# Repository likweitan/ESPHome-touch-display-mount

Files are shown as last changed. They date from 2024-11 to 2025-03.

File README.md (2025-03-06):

# 2.8" ILI9341 Touch Display Enclosure for ESP32 with Home Assistant Integration

This project provides ESPHome config files and 3D-printable files for an enclosure designed to house a 2.8" ILI9341 touch display. Compatible with standalone 2.8" ILI9341 touch display connected to an ESP32 board or using the ESP32-2432S028 (integrating an ESP32 Wroom module and ILI9341 display on one board), this setup serves as an external, touchscreen-enabled display for your Home Assistant environment.

The enclosure is designed for mounting beneath a desk and includes a swivel joint, allowing for easy adjustments to the viewing angle while keeping all cables neatly concealed for a clean, streamlined look. The touchscreen offers multiple customizable buttons linked to Home Assistant automations, making it easy to control functions such as lighting—and you’re free to create additional buttons as desired.

The joint supports an adjustable tilt of +/- 35 degrees up and down. The display’s positioning tension can be fine-tuned by adjusting the screw tightness. The screw hole is deliberately sized slightly smaller than the M4 screw, requiring a bit of force during insertion to ensure a secure hold that prevents any looseness.

Simply print the files and flash the firmware to the ESP using ESPHome, connect it to Home Assistant.

The images show the version with an ESP32-2432S028. I recommend using the ESP32-2432S028 as its just the power cable you need to pass-thru into the case and everything else is hidden. Down below you'll find some images of the ILI9341 display with an external ESP32.

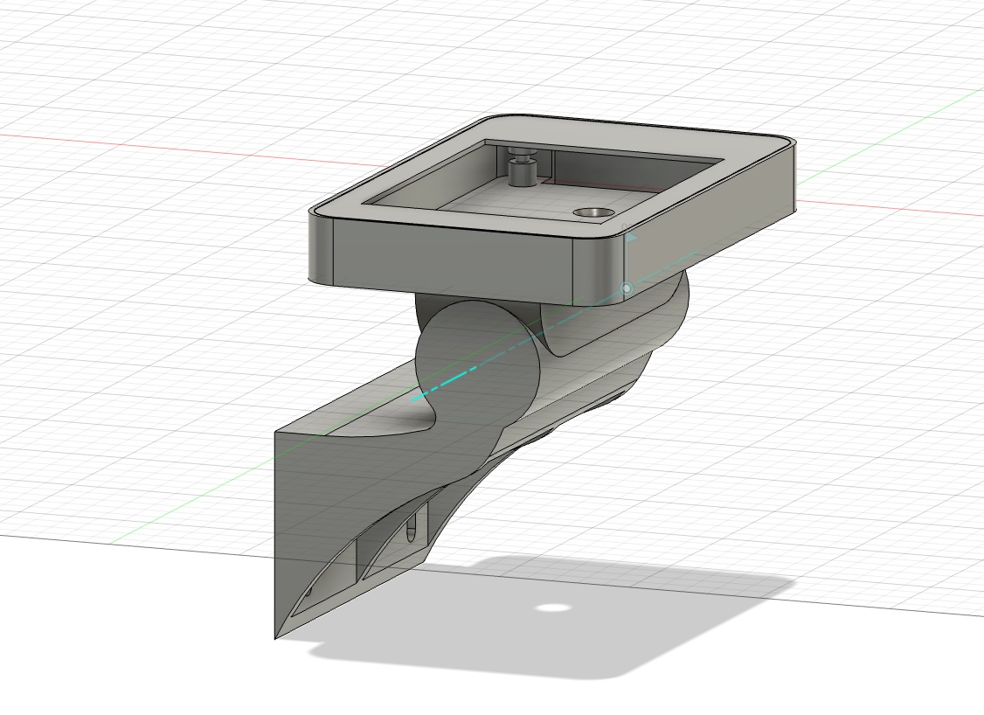
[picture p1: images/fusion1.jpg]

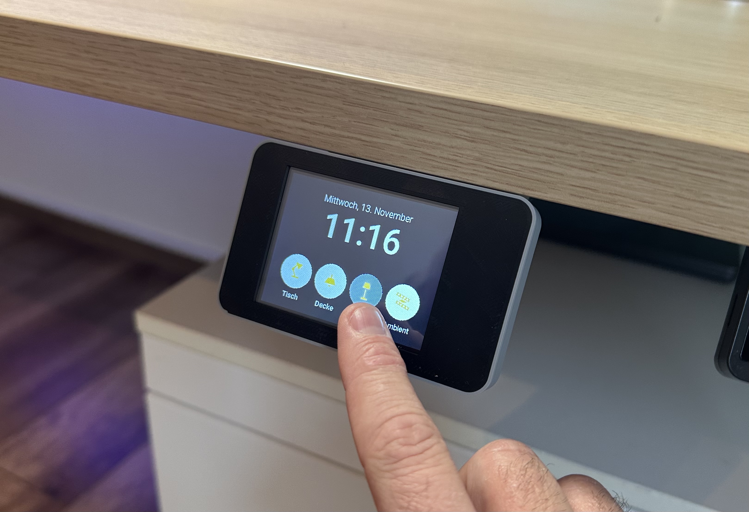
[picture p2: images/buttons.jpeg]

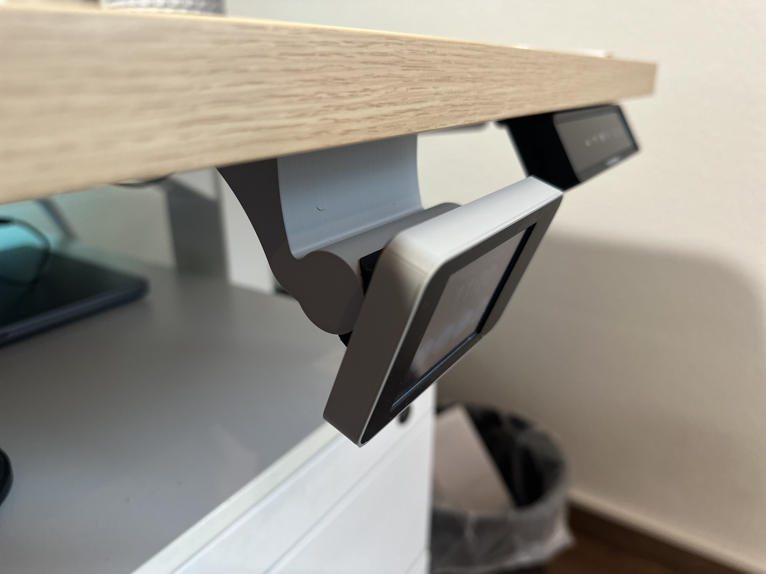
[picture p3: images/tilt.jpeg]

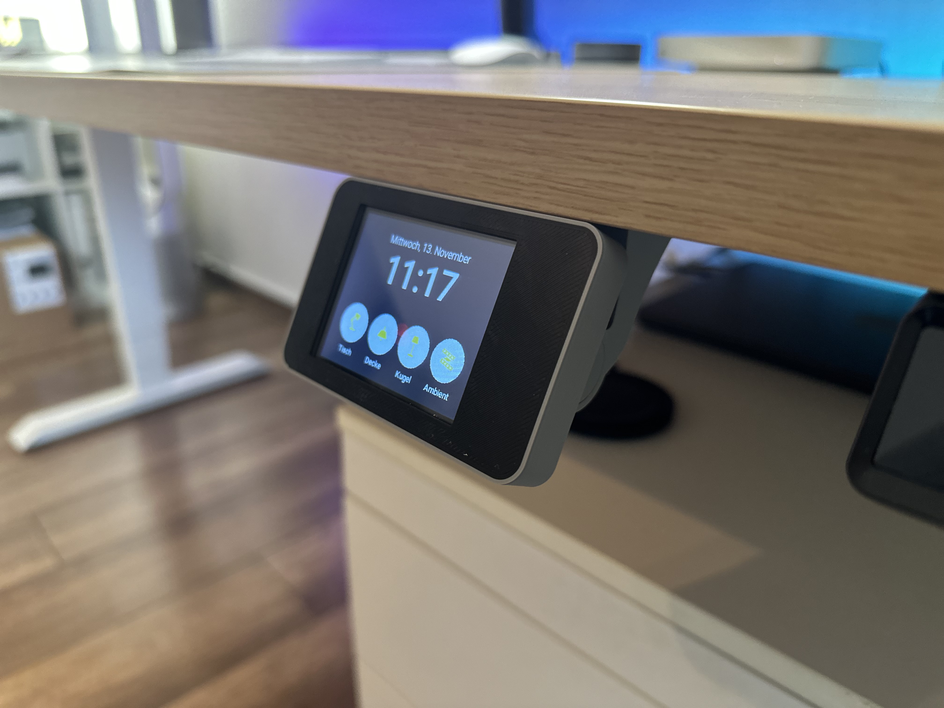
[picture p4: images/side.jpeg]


### Features:

- Customizable 3D-printed enclosure with hidden cable design for a clean setup
- Swivel joint for adjustable viewing angles
- Supports 2.8" ILI9341 touch display, compatible with ESP32 or ESP32-2432S028 (includes ESP32 Wroom and display on one board)
- Connect to Home Assistant compatibility to control automations such as lighting
- Using [ESPHome](https://www.esphome.io) which makes it easy to code and modify for your needs

## Parts needed

| Part | Price | Comment |
|---|---|---|
| ESP32-2432S028			 | 15$ | 2.8" ILI9341 with integrated ESP |
| 2x M4 3.5x16 screw (flathead)| 0.10$ | Screws to connect the mount case with the base  |

or

| Part | Price | Comment |
|---|---|---|
| 2.8" ILI9341 			 | 8$ | 2.8" ILI9341 |
| ESP32 Wroom 32D 		 | 8$ | or some ESP32 |
| 2x M4 3.5x16 screw (flathead)| 0.10$ | Screws to connect the mount case with the base  |

## How
- Flash your ESP32 via ESPHome and use the yaml from the esphome folder. Adjust to your needs
- Print the parts. 
- Use two M4 screws to attach the display case and the base
- *Connect all pins (when using a solo display with an ESP32)

## HomeAssistant
- Create some automations in home assistant using the exposed buttons as trigger.
<br/>
<br/>
<br/>
# Options

## a) Using an ESP32-2432S028
Simply connect to USB and flash the ESP using the yml file in the esphome directory. If your board is designed different check the pin layout

| ESP32-2432S028 | PIN | Comment |
|---|---|---|
| LCD | | |
| clk_pin | GPIO14 | SPI LCD Clock |
| mosi_pin | GPIO13 | SPI LCD MOSI (sometimes also labeled as SDI) |
| miso_pin 	 		 | GPIO12 | SPI LCD MISO (sometimes also labeled as SDO	 |
| cs_pin | GPIO15 | Display CS |
| dc_pin | GPIO2 | Display DC |
| Touchscreen | | |
| clk_pin | GPIO25 | SPI Touchscreen Clock |
| mosi_pin | GPIO32 | SPI Touchscreen MOSI (sometimes also labeled as DIN) |
| miso_pin | GPIO39 | SPI Touchscreen MISO (sometimes also labeled as DO)  |
| cs_pin | GPIO33 | Touchscreen CS |
| interrupt_pin | GPIO36 | Touchscreen Interrupt |
| LED | | |
| ledc | GPIO21 | Backlight LED display |
| ledc | GPIO4 | Onboard LED (not used for this project) |

To power the device, use the VIN and GND pins from the JST port (typically provided with a JST-to-pin cable). Pass the cable through the case using the hole in the center which runs through the swivel joint and connect these ends to the 5V and GND wires of an old USB cable

## b) Using an 2.8" ILI9141 standalone connected to an ESP32 Wroom 32D
Follow the connection diagram, which shows how to put everything together.

| ILI9341 | PIN  ESP32 | Comment |
|---|---|---|
| GND | GND | Ground |
| VCC | 3.3V | Power |
| LCD | | |
| SCK | GPIO18 | SPI LCD Clock |
| SDI (MOSI) | GPIO23 | SPI LCD MOSI (sometimes also labeled as SDI) |
| SDOK (MISO) 	 	 | GPIO19 | SPI LCD MISO (sometimes also labeled as SDO	 |
| CS | GPIO27 | Display CS |
| D/C | GPIO26 | Display DC |
| RESET | GPI16 | Display Reset |
| Touchscreen | | |
| T_CLK | GPIO25 | SPI Touchscreen Clock |
| T_DO | GPIO35 | SPI Touchscreen MOSI (sometimes also labeled as DIN) |
| T_DIN | GPIO32 | SPI Touchscreen MISO (sometimes also labeled as DO)  |
| T_CS | GPIO33 | Touchscreen CS |
| T_IRQ | GPIO34 | Touchscreen Interrupt |
| LED | | |
| ledc | GPIO4 | Backlight LED display |

## 3D Print
See folder print to get all SLT files and the fusion360 file. Feel free to adjust and remix

# DISCLAIMER
This project is to be considered as a work in progress. 
Feel free to adjust and remix the 3D cover to your needs. Its designed in Fusion 360, see fusion 360 file in the 3d_print folder.

# Other
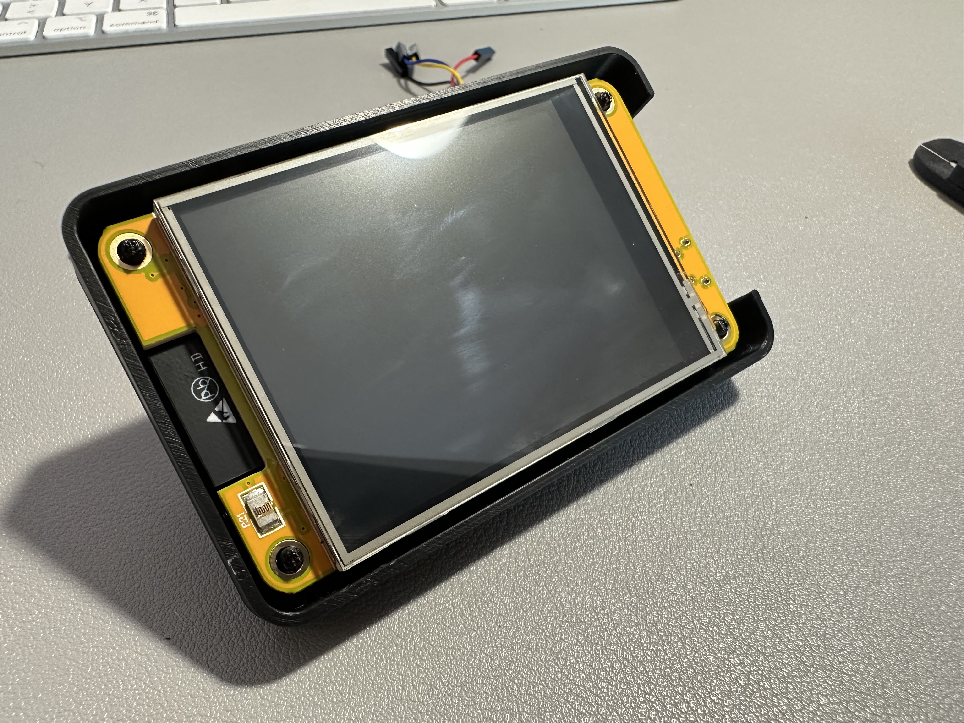
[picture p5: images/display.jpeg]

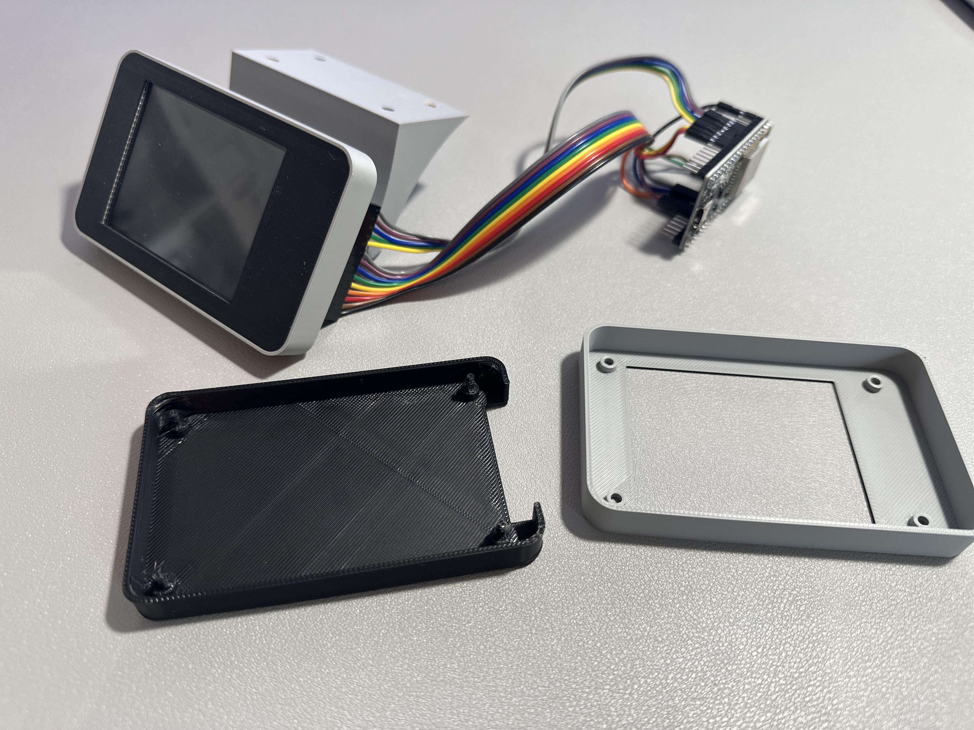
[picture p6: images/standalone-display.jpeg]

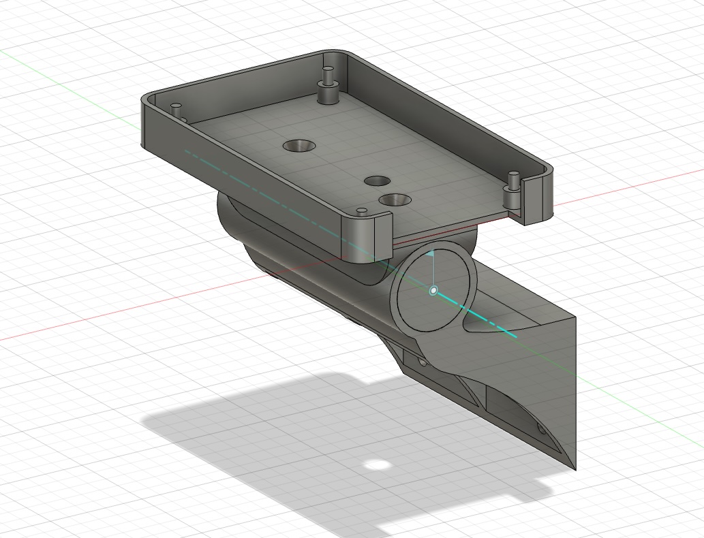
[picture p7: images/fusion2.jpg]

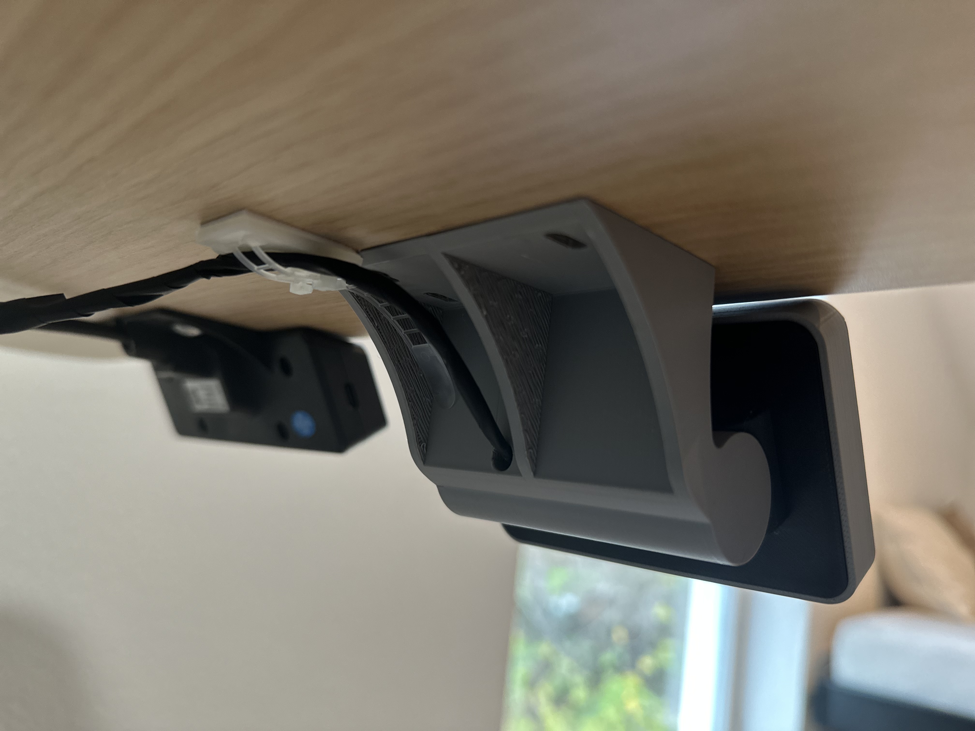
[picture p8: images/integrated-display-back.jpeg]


# More projects
Looking for more cool projects using this display? Check out the [LoctekMotion Touch Display GitHub repository](https://github.com/3DJupp/LoctekMotion-TouchDisplay)! This awesome project takes the same 2.8" ILI9341 touchscreen setup and repurposes it—not for lights, but for controlling a height-adjustable Flexispot desk with ease. If you're into smart home automation and custom builds, it's definitely worth a look!

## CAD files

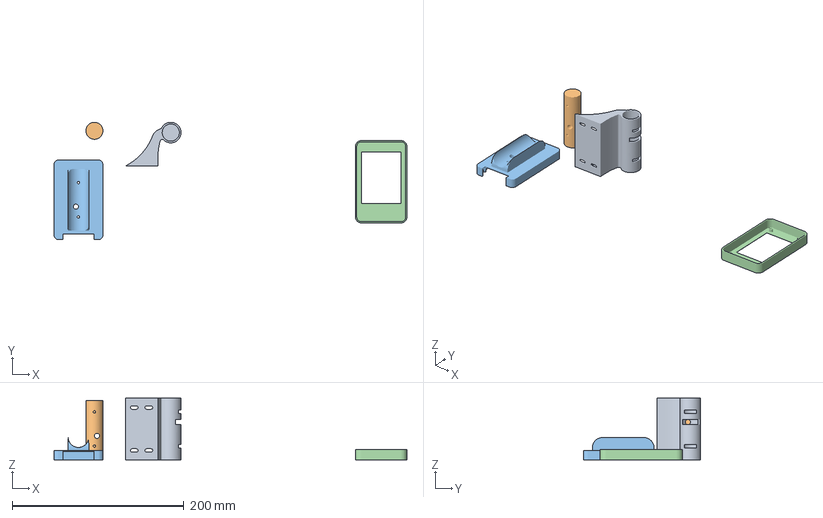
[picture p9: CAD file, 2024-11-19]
3d_print/ESP32-2432S028/mount.3mf
411.3 x 136.8 x 72.0 mm
table-mount.stl
locking-body.stl
inner-body.stl
outer-body.stl

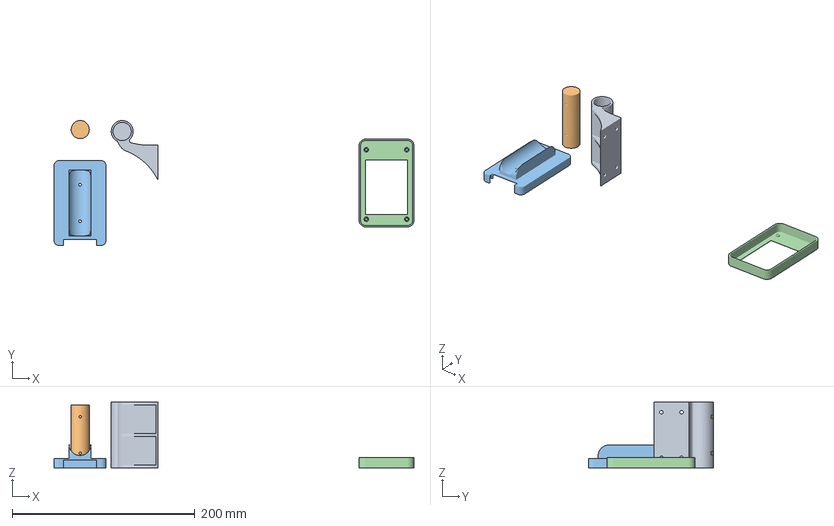
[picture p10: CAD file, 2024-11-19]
3d_print/ILI9341-only-display/mount.3mf
394.1 x 136.8 x 72.0 mm
table-mount.stl
locking-body.stl
inner-body.stl
outer-body.stl

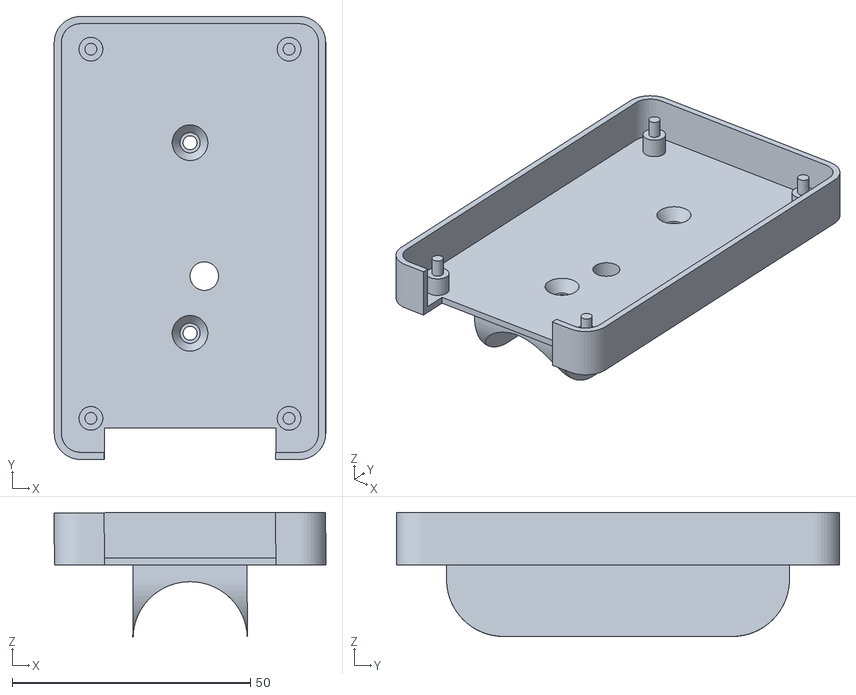
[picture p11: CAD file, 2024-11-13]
3d_print/ESP32-2432S028/inner-body.stl
57.0 x 93.0 x 26.1

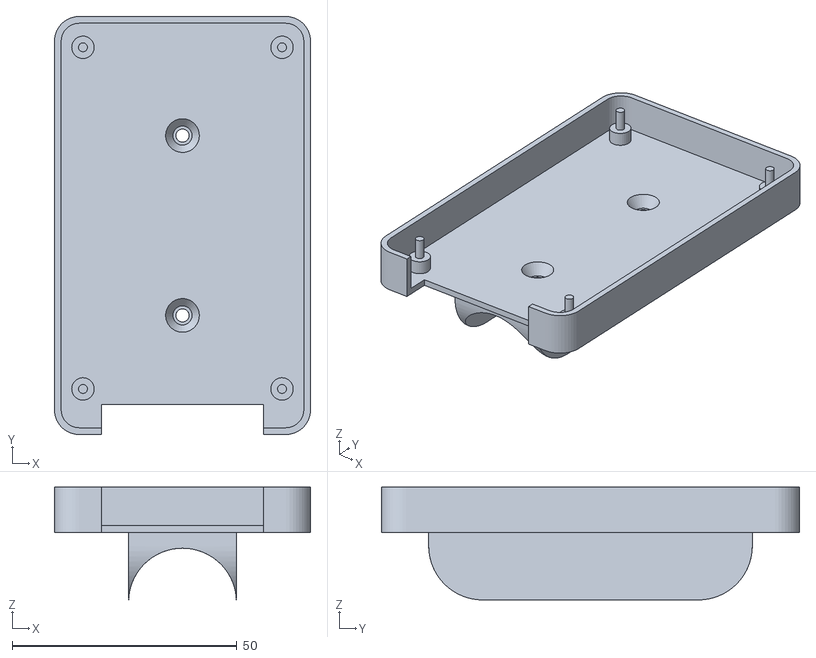
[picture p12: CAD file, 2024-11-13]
3d_print/ILI9341-only-display/inner-body.stl
57.0 x 93.0 x 25.1

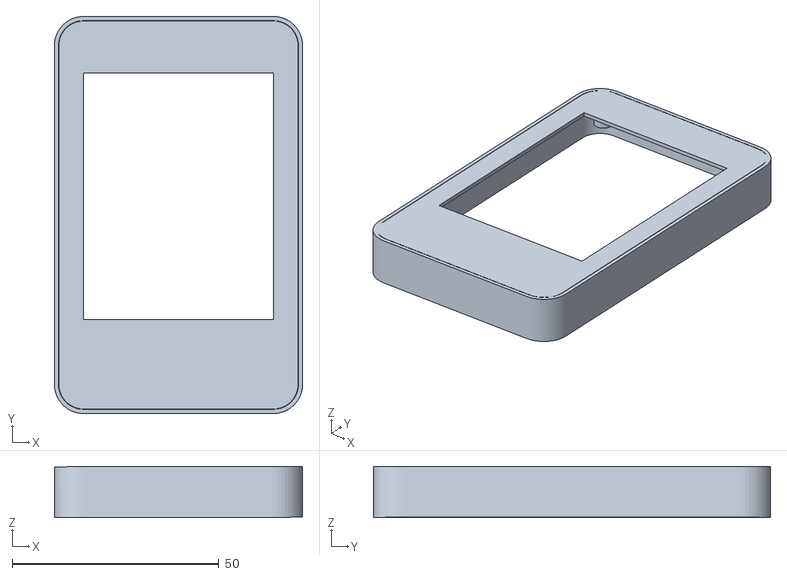
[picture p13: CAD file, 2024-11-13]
3d_print/ESP32-2432S028/outer-body.stl
60.1 x 96.1 x 12.4

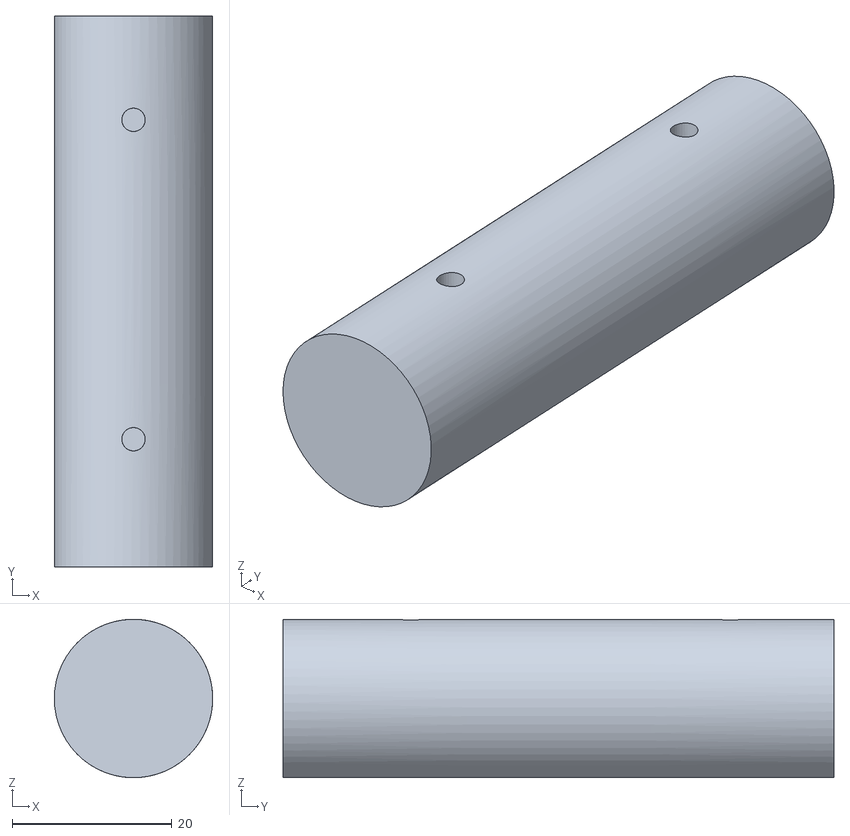
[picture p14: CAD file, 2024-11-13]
3d_print/ILI9341-only-display/locking-body.stl
19.8 x 69.0 x 19.8

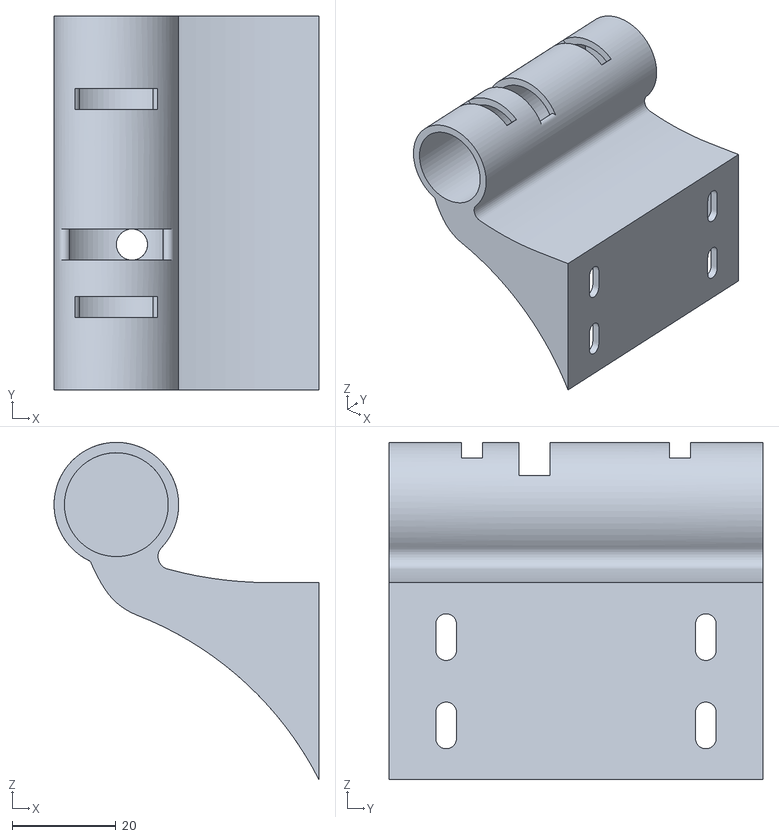
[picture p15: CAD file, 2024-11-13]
3d_print/ESP32-2432S028/table-mount.stl
51.0 x 72.0 x 64.9

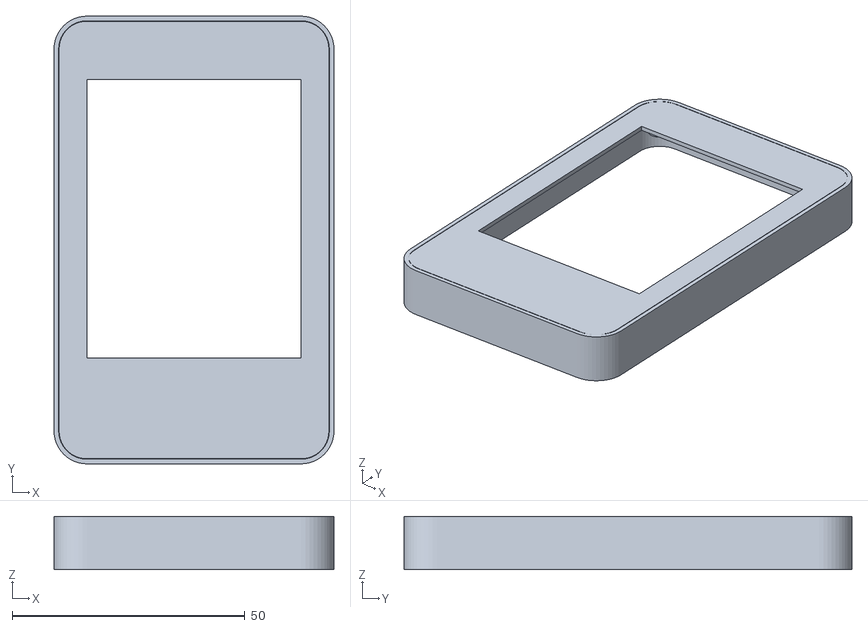
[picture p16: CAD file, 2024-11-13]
3d_print/ILI9341-only-display/outer-body.stl
60.1 x 96.1 x 11.4

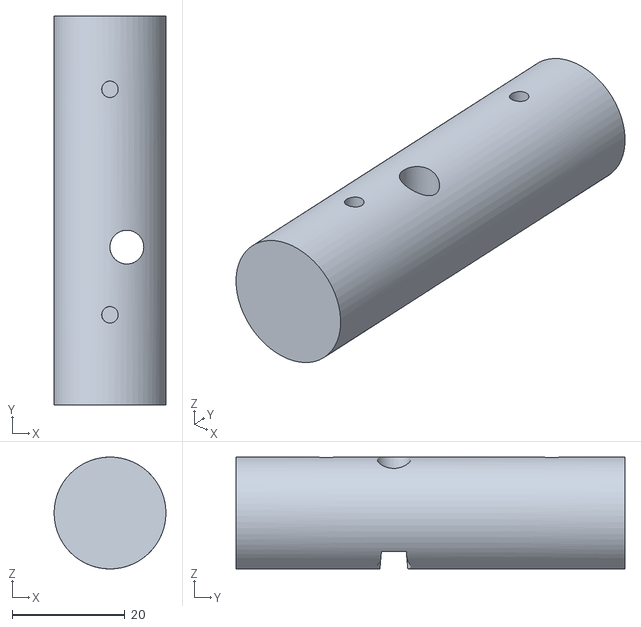
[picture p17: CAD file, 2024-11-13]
3d_print/ESP32-2432S028/locking-body.stl
19.8 x 69.0 x 19.8

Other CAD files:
3d_print/ILI9341-only-display/table-mount.stl
3d_print/ESP32-2432S028/touch-display.f3d
3d_print/ILI9341-only-display/touch-display.f3d

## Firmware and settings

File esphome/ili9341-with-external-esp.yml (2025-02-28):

esphome:
  name: smartdisplay
  friendly_name: SmartDisplay

esp32:
  board: esp32dev
  framework:
    type: arduino

logger:

api:
  encryption:
    key: "XXXXXXXXXXXXXXXXXXXXX/LI="

ota:
  - platform: esphome
    password: "XXXXXXXXXXXXXXXXXXXXX"

wifi:
  ssid: !secret wifi_ssid
  password: !secret wifi_password
  ap:
    ssid: "Smartdisplay Fallback Hotspot"
    password: "XXXXXXXXXXXXXXXXXXXXX"

captive_portal:

time:
  - platform: homeassistant
    id: homeassistant_time
    on_time:
      - seconds: 0
        minutes: /1 # Update every minute
        then:
          - component.update: my_display    

font: 

  # gfonts://family[@weight]
  - file: "gfonts://Roboto@500"
    id: big_text
    size: 60
    bpp: 4
    glyphs:
      ['&', '@', '!', ',', '.', '?', '"', '%', '(', ')', '+', '-', '_', ':', '°', '0',
       '1', '2', '3', '4', '5', '6', '7', '8', '9', 'A', 'B', 'C', 'D', 'E',
       'F', 'G', 'H', 'I', 'J', 'K', 'L', 'M', 'N', 'O', 'P', 'Q', 'R', 'S',
       'T', 'U', 'V', 'W', 'X', 'Y', 'Z', ' ', 'a', 'b', 'c', 'd', 'e', 'f',
       'g', 'h', 'i', 'j', 'k', 'l', 'm', 'n', 'o', 'p', 'q', 'r', 's', 't',
       'u', 'v', 'w', 'x', 'y', 'z','å', 'Ä', 'ä', 'Ö', 'ö', 'Ü', 'ü', '/']

  # gfonts://family[@weight]
  - file: "gfonts://Roboto@300"
    id: notice_text
    size: 16
    bpp: 4
    glyphs:
      ['&', '@', '!', ',', '.', '?', '"', '%', '(', ')', '+', '-', '_', ':', '°', '0',
       '1', '2', '3', '4', '5', '6', '7', '8', '9', 'A', 'B', 'C', 'D', 'E',
       'F', 'G', 'H', 'I', 'J', 'K', 'L', 'M', 'N', 'O', 'P', 'Q', 'R', 'S',
       'T', 'U', 'V', 'W', 'X', 'Y', 'Z', ' ', 'a', 'b', 'c', 'd', 'e', 'f',
       'g', 'h', 'i', 'j', 'k', 'l', 'm', 'n', 'o', 'p', 'q', 'r', 's', 't',
       'u', 'v', 'w', 'x', 'y', 'z','å', 'Ä', 'ä', 'Ö', 'ö', 'Ü', 'ü', '/']     

  # gfonts://family[@weight]
  - file: "gfonts://Roboto@400"
    id: label
    size: 13
    bpp: 4
    glyphs:
      ['&', '@', '!', ',', '.', '?', '"', '%', '(', ')', '+', '-', '_', ':', '°', '0',
       '1', '2', '3', '4', '5', '6', '7', '8', '9', 'A', 'B', 'C', 'D', 'E',
       'F', 'G', 'H', 'I', 'J', 'K', 'L', 'M', 'N', 'O', 'P', 'Q', 'R', 'S',
       'T', 'U', 'V', 'W', 'X', 'Y', 'Z', ' ', 'a', 'b', 'c', 'd', 'e', 'f',
       'g', 'h', 'i', 'j', 'k', 'l', 'm', 'n', 'o', 'p', 'q', 'r', 's', 't',
       'u', 'v', 'w', 'x', 'y', 'z','å', 'Ä', 'ä', 'Ö', 'ö', 'Ü', 'ü', '/']            

  - file: 'fonts/materialdesignicons-webfont.ttf'
    id: materialdesign_icons
    size: 35
    glyphs: ["\U000F095F", "\U000F0769", "\U000F08DD","\U000F1051"] # Get them from https://github.com/Templarian/MaterialDesign-Webfont/blob/master/fonts/materialdesignicons-webfont.ttf and copy to a folder /fonts

          
color:
  - id: ACTIVE
    hex: "FEC600"  
  - id: INACTIVE
    hex: "808080"  

# If you want a background image for your screen you can uncomment the next lines. Keep in mind rendering images slows down refresh of the display
#image:
#  - file: "images/my_background_image.jpg"
#    id: background
#    type: RGB565

sensor:
  - platform: wifi_signal
    name: "Wifi Signal"
    update_interval: 600s  
  - platform: uptime
    name: "Uptime"
    id: uptime_s
    update_interval: 15s       

binary_sensor:
# Adjust touchscreen touch areas if needed
# To trigger button actions use HA and just create an automation that uses the exposed buttons as triggers on change
  - platform: status
    name: "Node Status"
    id: system_status
  - platform: touchscreen
    name: Button 1 # exposes a button to HA
    x_min: 190
    x_max: 268    
    y_min: 18
    y_max: 63
  - platform: touchscreen
    name: Button 2 # exposes a button to HA
    x_min: 190
    x_max: 268
    y_min: 72
    y_max: 115    
  - platform: touchscreen
    name: Button 3 # exposes a button to HA
    x_min: 190
    x_max: 268     
    y_min: 126
    y_max: 169
  - platform: touchscreen
    name: Button 4 # exposes a button to HA
    x_min: 190
    x_max: 268     
    y_min: 178
    y_max: 224
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

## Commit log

2024-11-13 have fun
    [inner-body.stl, locking-body.stl, outer-body.stl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]
2024-11-13 added how to power the ESP32-2432S028
2024-11-19 added files for bambu studio
    [mount.3mf]
2025-01-02 fixed calibration values
2025-02-28 bugfix display issue since esphome 2025.2, thanks @3DJupp
    [esp32-2432s028.yml, ili9341-with-external-esp.yml]
2025-06-02 add Material Design Icons font file
